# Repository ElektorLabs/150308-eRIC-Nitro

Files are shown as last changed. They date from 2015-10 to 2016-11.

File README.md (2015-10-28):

150308 eRIC Nitro
=================

Arduino Micro compatible module with on-board LPRS eRIC low-power smart radio module. 
Supports eRIC4 (433 MHz) and eRIC9 (865/915 MHz) modules.

The board offers several operating modes:

- MCU controls eRIC through hardware UART

- MCU controls eRIC through software UART

- MCU cooperates with eRIC, eRIC controlled by PC 

Note that eRIC modules can function fully stand-alone, without any help from a
microcontroller. This board can handle that too.

The board is included in the Elektor Arduino Boards Package available at https://github.com/ElektorLabs/Arduino/

www.elektor-labs.com/eric-nitro

www.elektor.com

www.elektor-magazine.com

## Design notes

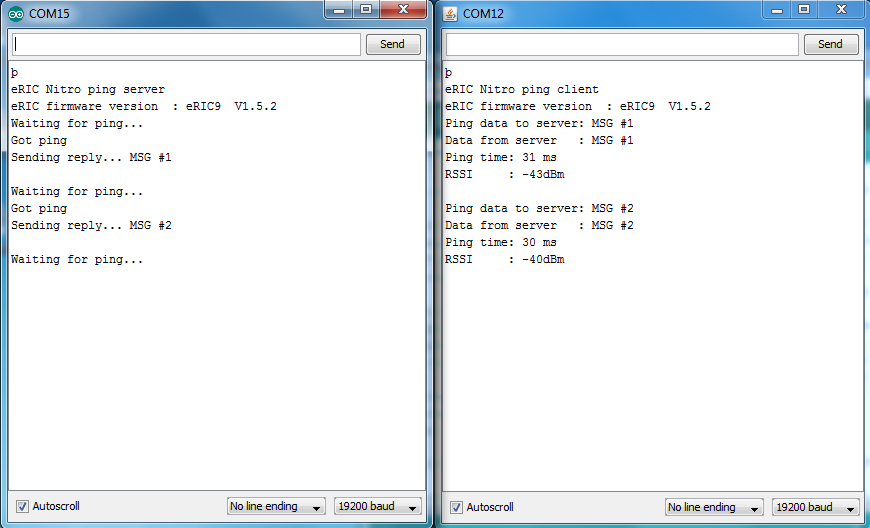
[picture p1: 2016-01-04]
Software/Arduino/eRIC_ping_server/TerminalImages.png

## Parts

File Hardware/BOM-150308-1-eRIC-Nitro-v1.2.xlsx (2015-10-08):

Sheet: BOM
BOM::150308-1::eRIC Nitro::v1.2
Description | Manufacturer | Reference | Footprint | Designation | Qnt | Farnell | Digikey | RS | BOMformul | Comments | BOM for editors
Resistor (5%, 50 V, 0.1 W, 0603) |  |  |  |  | 72 |  |  |  | Resistor (5%, 50 V, 0.1 W, 0603)
100 Ω | Bourns | CR0603-JW-102GLF | 0603-RES | R5, R6 | 2 | 2008355 |  |  | R5, R6 = 100 Ω
1 kΩ | Bourns | CR0603-JW-101GLF | 0603-RES | R1 | 1 | 2008349 |  |  | R1 = 1 kΩ
10 kΩ | Bourns | CR0603-JW-103ELF | 0603-RES | R2, R4, R7 | 3 | 2008360 |  |  | R2, R4, R7 = 10 kΩ
10 kΩ | Bourns | CR0603-JW-103ELF | 0603-RES | R3 | Not loaded | 2008360 |  |  | R3 = 10 kΩ
Capacitor |  |  |  |  | 34 |  |  |  | Capacitor
100 nF, 0603 | Multicomp | MC0603B104K500CT | 0603-CAP | C1, C2, C3, C4, C5, C6 | 6 | 1759122 |  |  | C1, C2, C3, C4, C5, C6 = 100 nF, 0603
10 µF, 16 V, tantalum | Kemet | T491A106K016AT | EIA3216 | C7, C8 | 2 | 1457414 |  |  | C7, C8 = 10 µF, 16 V, tantalum
Inductor |  |  |  |  | 23 |  |  |  | Inductor
10 µH, 0603 | TDK | MLZ1608M100WT | 0603-CAP | L1 | 1 | 2215635 |  |  | L1 = 10 µH, 0603
Semiconductor |  |  |  |  | 1 |  |  |  | Semiconductor
ATmega328P-AU | Atmel | ATMEGA328P-AU | TQFP32-08 | IC1 | 1 | 1715486 |  |  | IC1 = ATmega328P-AU
MIC5205-3.3 | Micrel | MIC5205-3.3YM5 TR | SOT23-5 | IC2 | 1 | 1663083 |  |  | IC2 = MIC5205-3.3
RB751 | ON Semiconductor | RB751S40T1G | SOD-523 | D1, D2, D3 | 3 | 2317437 |  |  | D1, D2, D3 = RB751
LED, green, 0603 | Kingbright | KPT-1608SGC | 0603-LED-ALT1 | LED1 | 1 | 2099223 |  |  | LED1 = LED, green, 0603
Misc. |  |  |  |  | 14 |  |  |  | Misc.
Resonator 8 MHz, SMT | Murata | CSTCE8M00G52-R0 | RESONATOR-SMD-1:1 | X1 | 1 | 2443268 |  |  | X1 = Resonator 8 MHz, SMT
Pin header, 1x12, 0.1" pitch | Wurth | 61301211121 | 1X12 | K1, K2 | 2 | 2356162 |  |  | K1, K2 = Pin header, 1x12, 0.1" pitch
Pin header, 1x2, 0.1" pitch | Wurth | 61300211121 | 1X02 | K3 | 1 | 2356153 |  |  | K3 = Pin header, 1x2, 0.1" pitch
Pin header, 1x2, 0.1" pitch | Wurth | 61300211121 | 1X02 | JP1 | 1 | 2356153 |  |  | JP1 = Pin header, 1x2, 0.1" pitch
Jumper, 2 way, 0.1", for JP6 | FCI | 68786-302LF | n/a |  | 1 | 1740371 |  |  | Jumper, 2 way, 0.1", for JP6
Pin header, 1x4, 0.1" pitch | Wurth | 61300411121 | 1X04 | K5 | 1 | 2356155 |  |  | K5 = Pin header, 1x4, 0.1" pitch
Pin header, 1x6, 0.1" pitch | Wurth | 61300611121 | 1X06 | K4 | 1 | 2356158 |  |  | K4 = Pin header, 1x6, 0.1" pitch
SMA edge connector | Molex | 73251-2120 | SMA-EDGE | K6 | 1 | 1909303 |  |  | K6 = SMA edge connector
Tactile switch | Multicomp | TM-533I-Q-T/R | TACTILE-SWITCH-SMD-ALT01 | S1 | 1 | 9471880 |  |  | S1 = Tactile switch
SP3T Slide Switch | C&K Components | AYZ0203AGRLC | AYZ0203 | S2 | 1 | 2319975 |  |  | S2 = SP3T Slide Switch
eRIC4 SoC Radio Transceiver | LPRS | ERIC4 | ERIC | MOD1 | 1 | 2362439 |  |  | MOD1 = eRIC4 SoC Radio Transceiver
eRIC9 SoC Radio Transceiver | LPRS | ERIC9 | ERIC | MOD1 | 1 | 2362440 |  |  | MOD1 = eRIC9 SoC Radio Transceiver
PCB 150308-1 v1.2 | Elektor | 150308-1 | n/a |  | 1 | n/a |  |  | PCB 150308-1 v1.2
Firmware 150308-11 | Elektor | 150308-11 |  |  | 1 |  |  |  | Firmware 150308-11
GREEN lines for board loaded with eRIC4 module.
BLUE lines for board loaded with eRIC9 module.

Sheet: history
DOCUMENT HISTORY
Date | Rev. | Author | Description

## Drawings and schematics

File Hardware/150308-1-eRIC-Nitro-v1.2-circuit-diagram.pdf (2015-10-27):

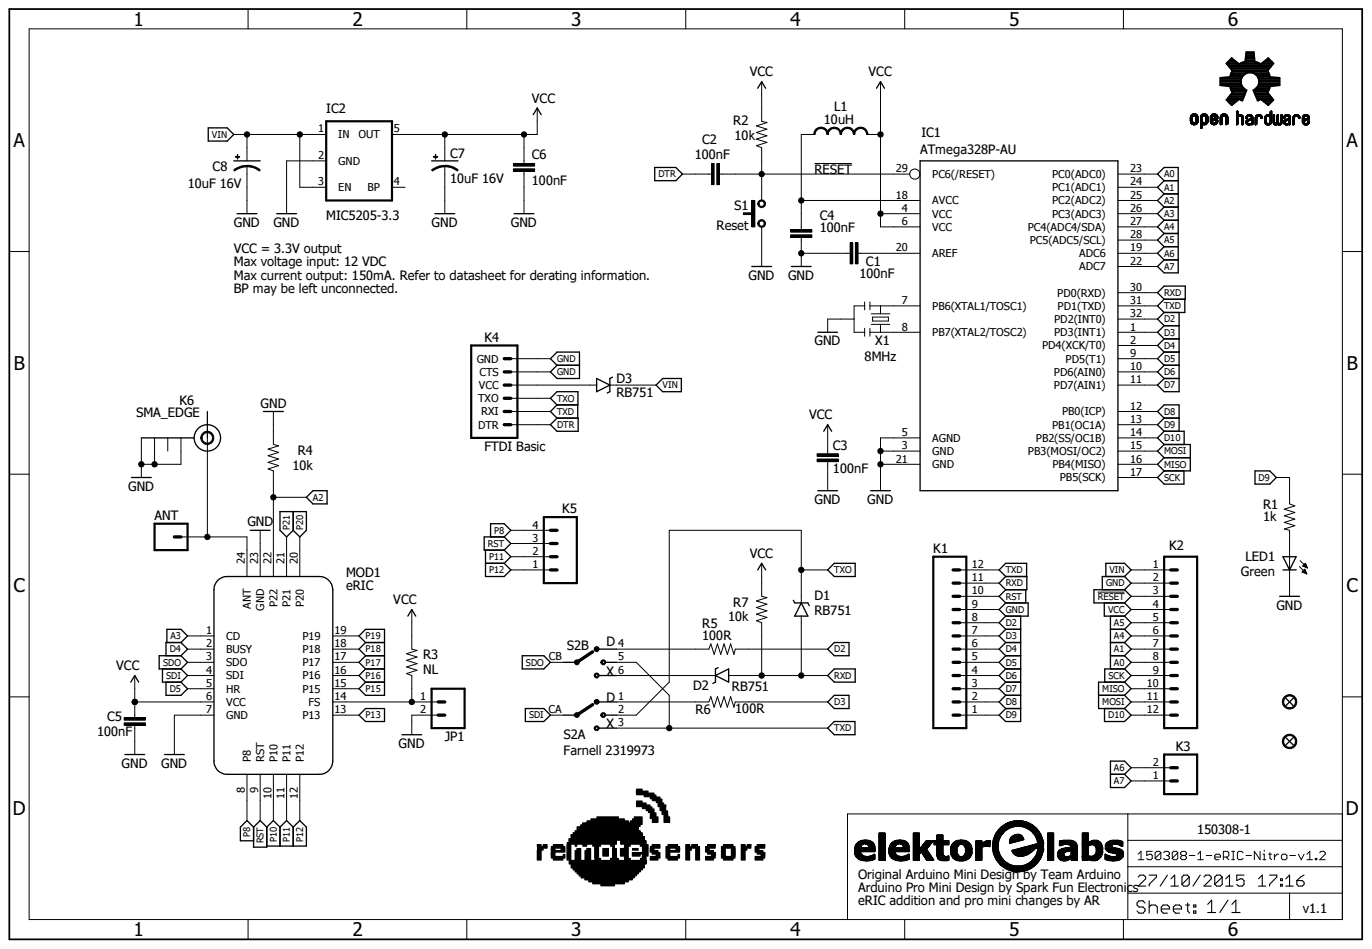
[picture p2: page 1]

VCC = 3.3V output
Max voltage input: 12 VDC
Max current output: 150mA. Refer to datasheet for derating information.
BP may be left unconnected.

Original Arduino Mini Design by Team Arduino
Arduino Pro Mini Design by Spark Fun Electronics
eRIC addition and pro mini changes by AR

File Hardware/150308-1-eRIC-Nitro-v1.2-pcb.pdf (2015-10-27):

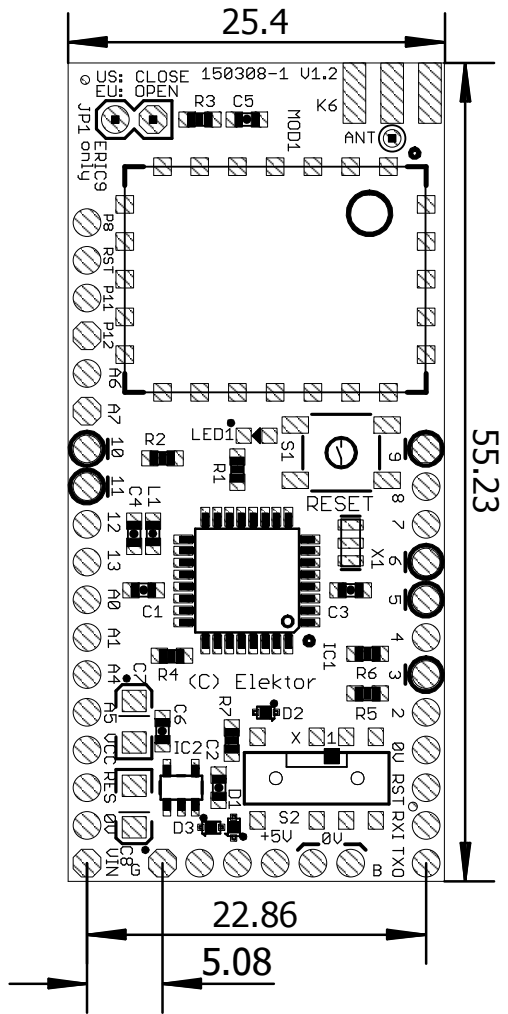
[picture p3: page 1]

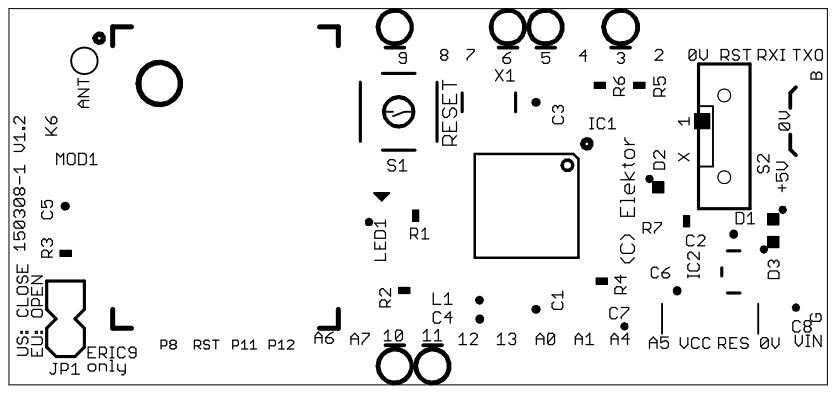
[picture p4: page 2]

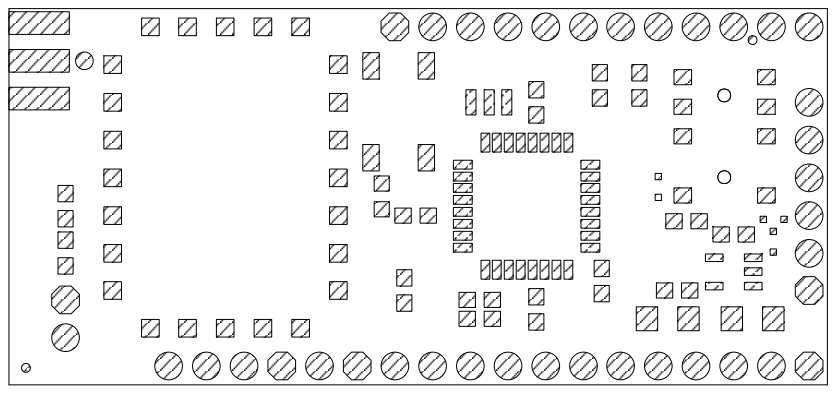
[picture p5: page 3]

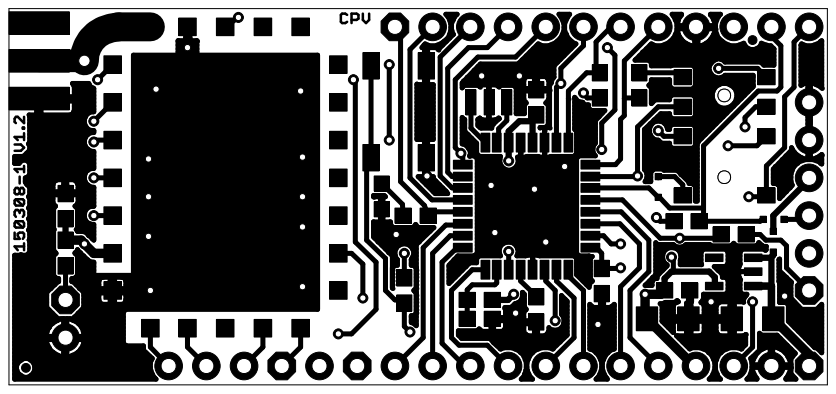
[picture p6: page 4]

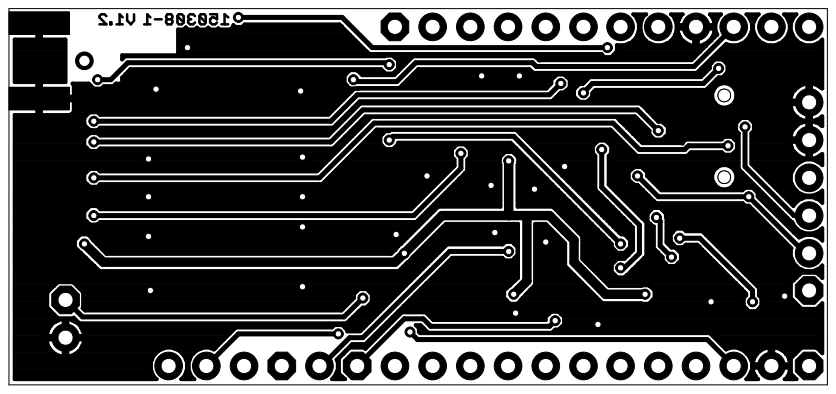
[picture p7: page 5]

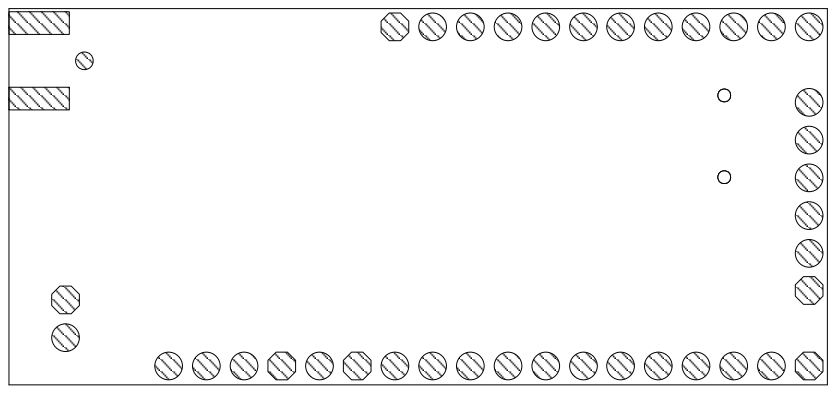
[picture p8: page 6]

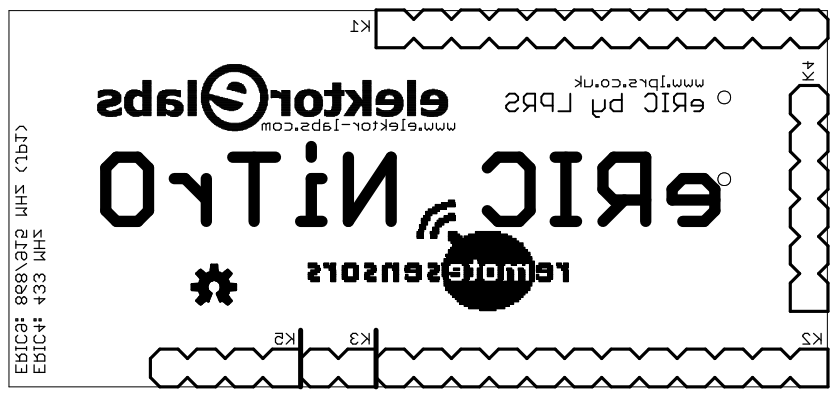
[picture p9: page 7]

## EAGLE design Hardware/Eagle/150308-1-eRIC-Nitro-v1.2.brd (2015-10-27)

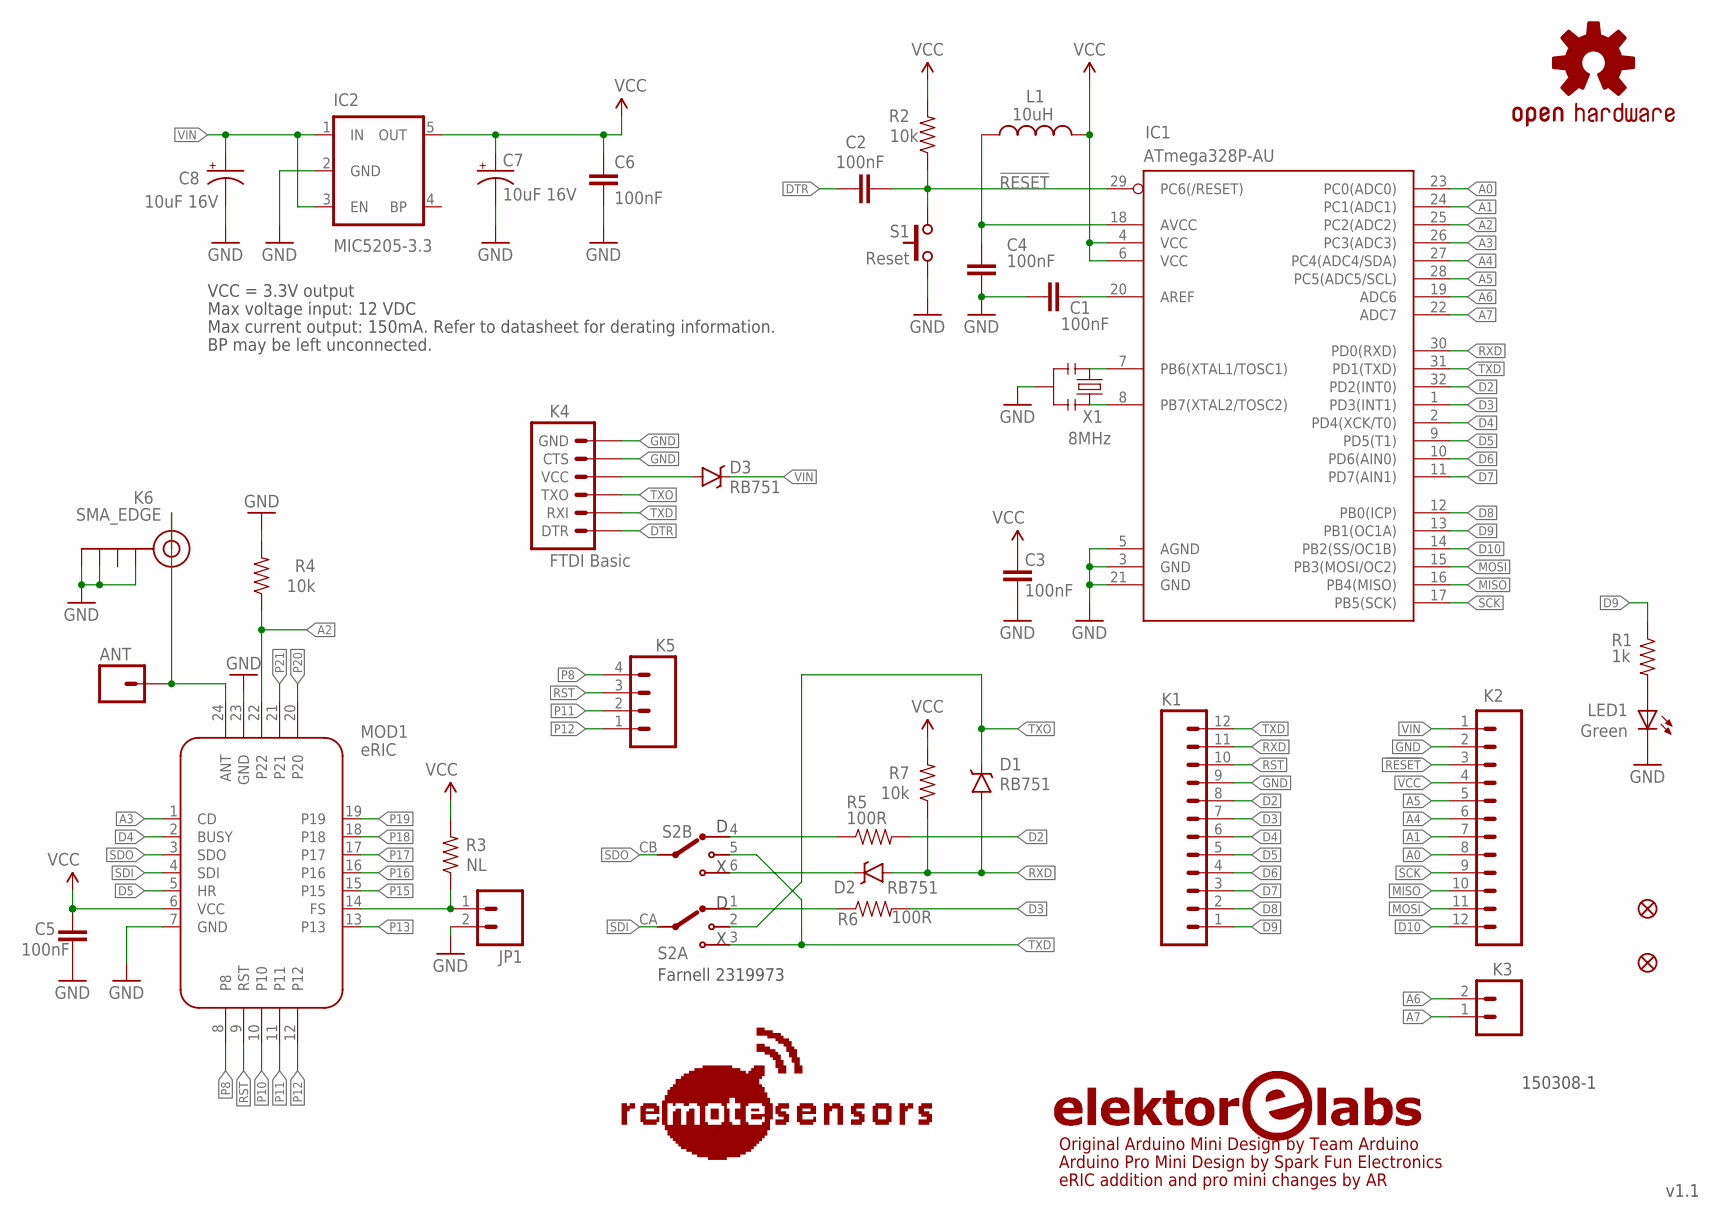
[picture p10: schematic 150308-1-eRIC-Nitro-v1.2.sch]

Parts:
ANT: M01PTH; 1X01-080
C1, C2, C3, C4, C5, C6: 100nF; 0603-CAP
C7, C8: 10uF 16V; EIA3216
D1, D2, D3: RB751; SOD-523
FID1, FID2: FIDUCIALUFIDUCIAL; MICRO-FIDUCIAL
IC1: ATmega328P-AU; TQFP32-08
IC2: MIC5205-3.3; SOT23-5
JP1: M02PTH; 1X02
K1, K2: M12PTH; 1X12
K3: M02PTH; 1X02
K4: FTDI Basic; 1X06
K5: M04PTH; 1X04
K6: SMA_EDGE; SMA-EDGE
L1: 10uH; 0603
LED1: Green; 0603-LED-ALT1
LOGO1: OSHW-LOGOS; OSHW-LOGO-S
LOGO2: LOGO-ELEKTOR-LABS-25MM; ELPP-LOGO-ELEKTOR-LABS-25MM
LOGO3: LOGO-REMOTE-SENSORS-17MM; LOGO-REMOTE-SENSORS2
MOD1: eRIC; ERIC
R1: 1k; 0603-RES
R2, R4, R7: 10k; 0603-RES
R3: NL; 0603-RES
R5, R6: 100R; 0603-RES
S1: Reset; TACTILE-SWITCH-SMD-ALT04
S2: AYZ0203AGRLC; AYZ0203
X1: 8MHz; RESONATOR-SMD

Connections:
!RESET!: C2.1, IC1.29 (PC6(/RESET)), K2.3, R2.1, S1.3 (2), S1.4 (2)
A0: IC1.23 (PC0(ADC0)), K2.8
A1: IC1.24 (PC1(ADC1)), K2.7
A2: IC1.25 (PC2(ADC2)), MOD1.22, R4.1
A3: IC1.26 (PC3(ADC3)), MOD1.1 (CD)
A4: IC1.27 (PC4(ADC4/SDA)), K2.6
A5: IC1.28 (PC5(ADC5/SCL)), K2.5
A6: IC1.19 (ADC6), K3.2
A7: IC1.22 (ADC7), K3.1
ANTENNE: ANT.1, K6.SIG (SIGNAL), MOD1.24 (ANT)
D2: IC1.32 (PD2(INT0)), K1.8, R5.2
D3: IC1.1 (PD3(INT1)), K1.7, R6.2
D4: IC1.2 (PD4(XCK/T0)), K1.6, MOD1.2 (BUSY)
D5: IC1.9 (PD5(T1)), K1.5, MOD1.5 (HR)
D6: IC1.10 (PD6(AIN0)), K1.4
D7: IC1.11 (PD7(AIN1)), K1.3
D8: IC1.12 (PB0(ICP)), K1.2
D9: IC1.13 (PB1(OC1A)), K1.1, R1.1
D10: IC1.14 (PB2(SS/OC1B)), K2.12
DTR: C2.2, K4.1 (DTR)
FS: JP1.1, MOD1.14 (FS), R3.1
GND: C1.1, C3.1, C4.1, C5.1, C6.2, C7.C (-), C8.C (-), IC1.3 (GND), IC1.5 (AGND), IC1.21 (GND), IC2.2 (GND), JP1.2, K1.9, K2.2, K4.5 (CTS), K4.6 (GND), K6.GND@0 (GND), K6.GND@2 (GND), K6.GND@3 (GND), LED1.C, MOD1.7 (GND), MOD1.23 (GND), R4.2, S1.1, S1.2 (1), X1.2
MISO: IC1.16 (PB4(MISO)), K2.10
MOSI: IC1.15 (PB3(MOSI/OC2)), K2.11
unnamed: IC1.8 (PB7(XTAL2/TOSC2)), X1.3
unnamed: IC1.7 (PB6(XTAL1/TOSC1)), X1.1
unnamed: C1.2, IC1.20 (AREF)
unnamed: C4.2, IC1.18 (AVCC), L1.1
unnamed: LED1.A, R1.2
unnamed: D3.A, K4.4 (VCC)
unnamed: R5.1, S2.4 (1)
unnamed: D2.C, S2.6 (3)
unnamed: R6.1, S2.1
P8: K5.4, MOD1.8
P10: MOD1.10
P11: K5.2, MOD1.11
P12: K5.1, MOD1.12
P13: MOD1.13
P15: MOD1.15
P16: MOD1.16
P17: MOD1.17
P18: MOD1.18
P19: MOD1.19
P20: MOD1.20
P21: MOD1.21
RST: K1.10, K5.3, MOD1.9 (RST)
RXD: D1.A, D2.A, IC1.30 (PD0(RXD)), K1.11, R7.1
SCK: IC1.17 (PB5(SCK)), K2.9
SDI: MOD1.4 (SDI), S2.CA (2)
SDO: MOD1.3 (SDO), S2.CB (2)
TXD: IC1.31 (PD1(TXD)), K1.12, K4.2 (RXI), S2.3, S2.5 (7)
TXO: D1.C, K4.3 (TXO), S2.2 (7)
VCC: C3.2, C5.2, C6.1, C7.A (+), IC1.4 (VCC), IC1.6 (VCC), IC2.5 (OUT), K2.4, L1.2, MOD1.6 (VCC), R2.2, R3.2, R7.2
VIN: C8.A (+), D3.C, IC2.1 (IN), IC2.3 (EN), K2.1

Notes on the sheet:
Original Arduino Mini Design by Team Arduino
Arduino Pro Mini Design by Spark Fun Electronics
Max voltage input: 12 VDC
Max current output: 150mA. Refer to datasheet for derating information.
VCC = 3.3V output
eRIC addition and pro mini changes by AR
Farnell 2319973
BP may be left unconnected.

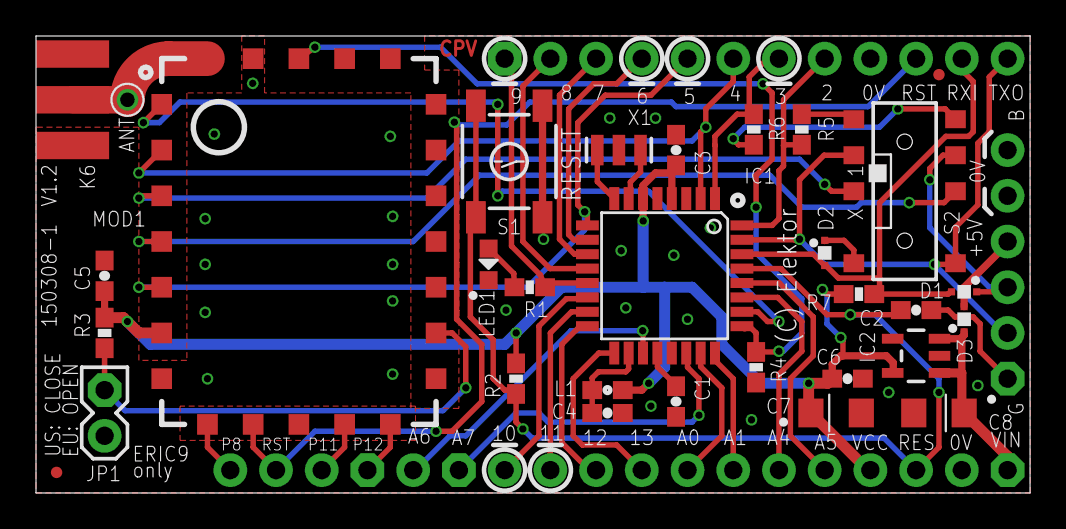
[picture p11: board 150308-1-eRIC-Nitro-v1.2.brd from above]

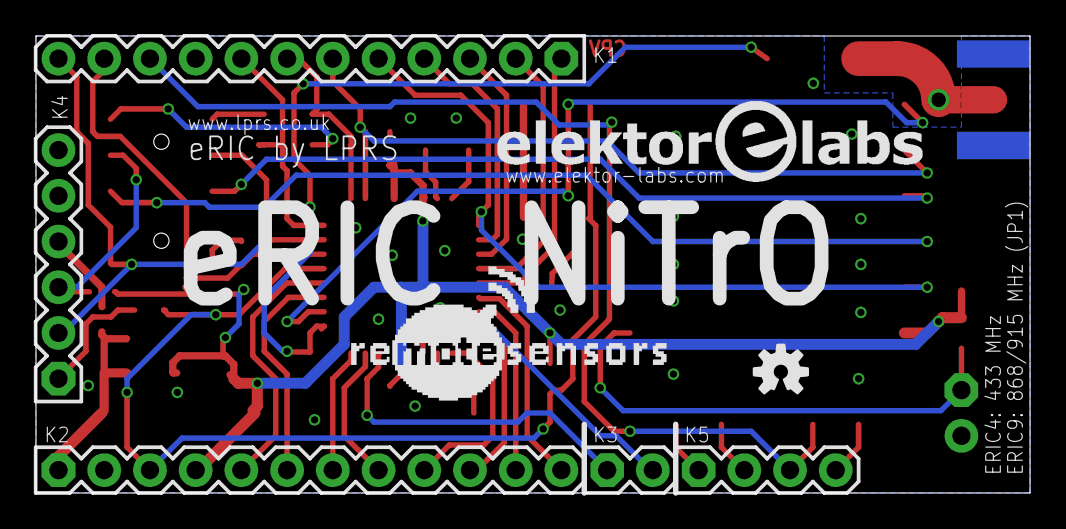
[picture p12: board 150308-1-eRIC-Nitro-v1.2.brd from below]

Board: 2 copper layers, 55.2 x 25.4 mm, 39 parts (8 on the bottom side), 45 nets.

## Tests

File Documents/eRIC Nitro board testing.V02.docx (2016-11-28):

# 1 Introduction

The purpose of this document is to describe how to configure the Nitro board for use with the LPRS “easyRadio Companion software” while describing a test sequence to verify the assembly of the eRIC Nitro board and to verify the eRIC module is capable of transmitting and receiving data from another eRIC module.

# 2 eRIC Nitro board testing

Suggested test sequence,

a) Test the eRIC module in standalone mode
b) Test the Arduino in standalone mode
c) Test the Arduino communication with the eRIC using Arduino software UART
d) Test the Arduino communication with the eRIC using Arduino hardware UART

## 2.1 Test setup – eRIC module in standalone mode

To test eRIC module in standalone mode on Nitro board (verifying part of the eRIC PCB design and PCB assembly), requires,

a) 1 x assembled Nitro board, fully populated including all components including SIL headers strip and wire antenna (see later)
b) 1 x FTDI – USB-serial cable (USB to UART cable with +3.3V TTL level UART signals e.g. Farnell TTL-232R-3V3 http://bit.ly/2gryNGJ )
c) 1 x female-female jumper or jumper cable
d) 1 x Windows PC
e) 1 x LPRS easyRadio Companion software (see later)

# 3 Test Procedure – step 1

1. At this point it is assumed that the Nitro board has been checked to confirm (at least) there are no short circuits between Nitro board Vin and GND (0V) pins and 3.3V and GND(0V) pins.
2. The LPRS website page http://www.lprs.co.uk/resource-centre/downloads/eric-software-datasheets/eros-4-files.html contains the documentation and software for the eRIC module

Download and install the easyRadio software from http://www.lprs.co.uk/assets/media/easyRadiosetup%204.0.5.exe

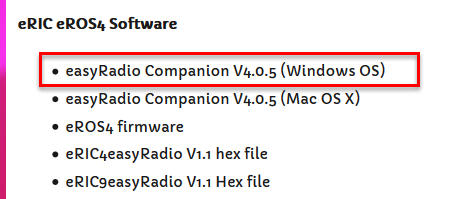
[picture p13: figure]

3. Get your FTDI cable ready. Don’t connect it to the Nitro or PC just yet and make sure there is no power applied to the board.
4. Get the Nitro board ready as follows,
a) Populate the Nitro board FTDI header (K4) with a male 6 pin header so that it can mate with the female end of a FTDI connector. The board below shows a SMA connector (6) added to the board but this is not necessary if using only a wire antenna

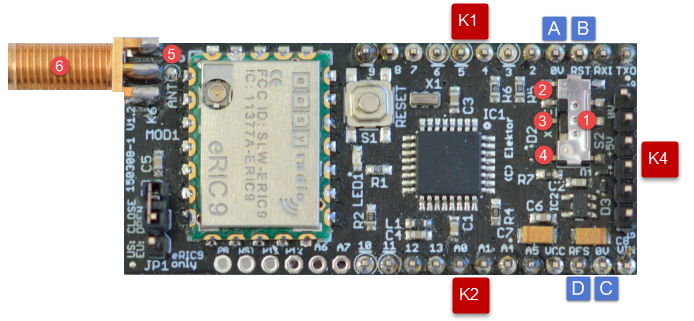
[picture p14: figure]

b) There are 2 options for a board level antenna. Either connect an SMA antenna (to 6) or solder a simple (¼ wavelength) wire antenna to the board (at 5). The antenna length for an eRIC9 module is 86mm. For a eRIC4 module it is 173mm.

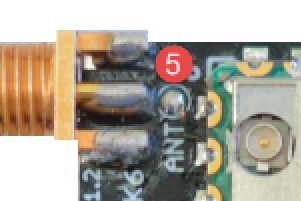
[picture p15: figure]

c) Using a jumper, connect the Nitro RES pin (D) to 0V (C), as this will force all ATMega328 pins into high impedance state when power is finally applied to the board.
  - Note: there is a separate reset pin (B) RST for the eRIC module. Leave this unconnected and do not confuse it with RES pin (D), which is the ATMega328 reset pin.
d) Put Nitro board switch S2 (1) into middle position (3) so that the SDO/SDI pins of the eRIC are directly connected to the FTDI header (K4) RXI/TXO pins, bypassing the ATMega328 RXD/TXD pins.

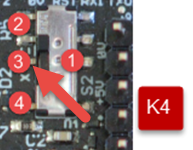
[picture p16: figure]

e) Connect the FTDI cable to the Nitro FTDI header (K4). Pay special attention to make sure the cable header polarity is correct – the FTDI GND pin (black cable) must mate with the Nitro FTDI header (K4) GND pin, and the FTDI +5V/VCC pin (red cable) must mate with the Nitro FTDI header (K4) +5V/VCC pin. Once this is done, connect USB end of FTDI cable to computer USB port. This will power up the Nitro board including the eRIC.

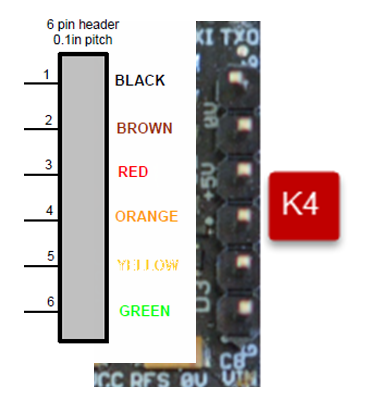
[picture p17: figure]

5. Start the easyRadio software

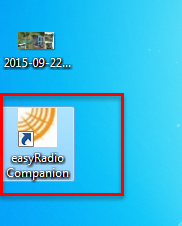
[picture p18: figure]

6. This will open a dialog box, but you can select “Not Now” to skip this section

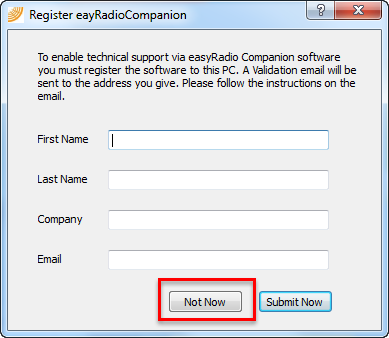
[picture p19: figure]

7. Select eRIC radio button (1) and then “OK” button (2) to select the eRIC module

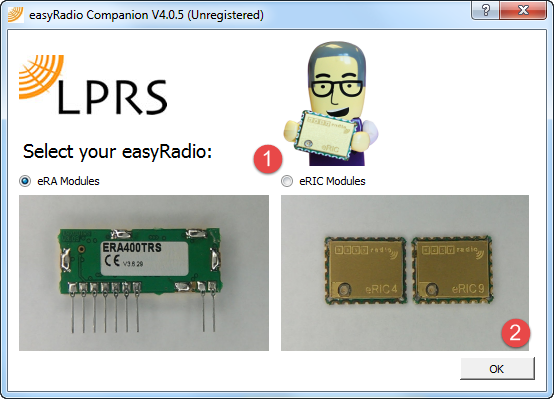
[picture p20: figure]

8. Next setup the FTDI serial connection settings from within the easyRadio software.
a) Select the appropriate port from drop down list (1)
b) Leave the baud rate(2) at whatever value it is set at, since the easyRadio software will try and auto detect the eRIC baud rate, and the value (2) may change.
c) Set handshaking as none (3)
d) Click on the “Open port” button to open the FTDI virtual COM port (4).

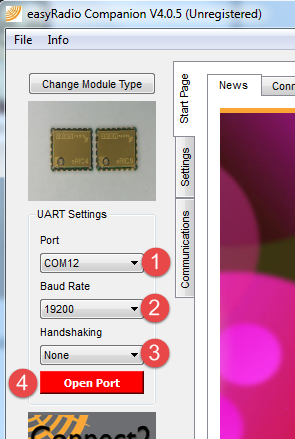
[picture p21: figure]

9. Click on the settings (1) and the then the module info (2) tabs.

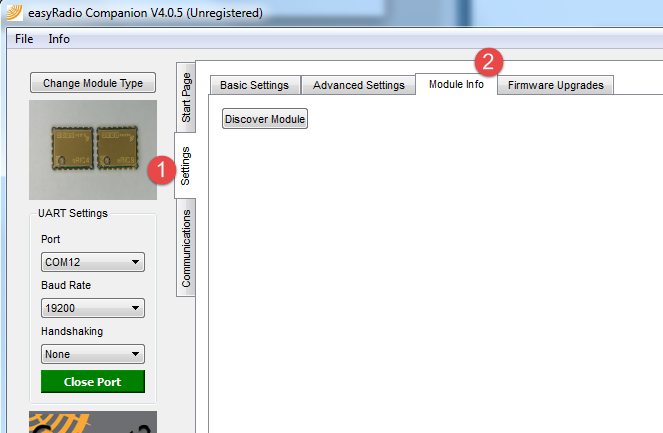
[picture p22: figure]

10. Click on “Discover Module” (1). The easyRadio software will try and autobaud connect to the eRIC module on the specified port.


If all is okay (i.e. eRIC not dead, no problems with FTDI cable TXD/RXD to eRIC SDI/SDO connections or power to eRIC etc.), then you should see a screen similar to the one below, where all of the information related to App Code, OS, BSL etc. has been read from the eRIC module over the FTDI TXD/RXD interface.


This is a good sign that the basic eRIC-FTDI electrical connections are good. To verify the PCB design and assembly further needs a second eRIC module and another set of test steps. See next section.

# 4 Test Procedure – step 2

Step 2 requires another Nitro board to be assembled and tested as per step 1. This will require a second FTDI cable and a second female-female jumper.

Confirm the 2nd Nitro board hardware by repeating actions 1, 3-10 from step 1 above. No action 2 is necessary if the easyRadio software has already been downloaded and installed. Both Nitro boards must be of same type i.e. both eRIC4, or both eRIC9, and both must have same firmware revision.

We can now test the RF interface.

1. Close all instances of the easyRadio software.
2. Remove FTDI cables from PC.
3. Connect first FTDI cable to 1st Nitro board and insert FTDI cable USB to PC.
4. Connect second FTDI cable to 2nd Nitro board and insert FTDI cable USB to PC.
5. Keep both Nitro board at least 30cm apart to avoid RF swamping i.e. avoid overloading Nitro 2 radio receiver with too large a signal from Nitro 1.
6. Open easyRadio software and repeat action 6, 7, 8 for 1st module. Then select communications tab (1)


7. Open second instance of easyRadio software and repeat action 6, 7, 8 for 2nd module. Then select communications tab (1) again in second instance. On your screen you might see something like this, (In this image we have 2 Nitro boards connected to COM port 12 and 15 on the test PC.)


8. On 1st instance of software at (1) type in a message to be sent to 2nd Nitro board, then click on Send button (2). If all is okay and Nitro 2 is receiving , then the message from Nitro 1 should appear on Nitro 2 at (3)


# 5 Document revisions

Revision | Description
V01 | Initial version
V02 | Updated to clarify switch and jumper configuration for eRIC Nitro use with LPRSTM easyRadio Companion software

=== end of document ===

eRIC Nitro Board testing and LPRS easyRadio Companion software setup V02

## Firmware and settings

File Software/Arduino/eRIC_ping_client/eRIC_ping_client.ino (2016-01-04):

/*
 * Part of Elektor project 150308 eRIC Nitro.
 *
 * Put S2 in position 'X'.
 * Software serial port on pins 2 & 3.
 * 3.3 V FTDI compatible USB-to-serial converter connected to K1 (D2, D3, GND),
 * +5V connected to K4 pin 4.
 * 
 * Sends ping messages to eRIC Nitro server. Receives returned ping from server
 * and prints time for transmit-receive round trip and also the received signal
 * strength of received message.
 * Does not use any hardware flow control between MCU and eRIC module.
 *
 * MCU communicates with eRIC module through hardware UART.
 * MCU communicates with PC through software UART.
 * Serial port settings: 19200n81
 *
 * AR, 03/01/2016
 *
 * Copyright (c) 2016 Elektor (www.elektor.com, www.elektor-labs.com).
 * All right reserved.
 *
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
 * You should have received a copy of the GNU Lesser General Public
 * License along with this library; if not, write to the Free Software
 * Foundation, Inc., 51 Franklin St, Fifth Floor, Boston, MA  02110-1301  USA
 */
/* 
 * Put S2 in position 'X' (close to D1).
 * Software serial port on pins 2 & 3.
 * 
 * Sends all known queries to eRIC module, one per second,
 * and forwards response to PC.
 */

#include <SoftwareSerial.h>

#define TIMEOUT                1000 
  // Timeout value - 1000milliseconds
#define ERIC_CMD_FIRMWARE      "ER_CMD#T3"
  // eRIC OS command to read module firmware version
#define ERIC_CMD_RSSI          "ER_CMD#T8"
  // eRIC OS command to read last message RSSI
#define ACK                    1
#define NO_ACK                 0
#define MAX_RF_PAYLOAD_SIZE    32 
  // We only want to use a small RF payload.
  // eRIC module can handle much larger RF payloads than this
#define ERROR_OK               1
#define ERROR_TIMEOUT          2
#define ERROR_CMD_NOT_RETURNED 3
#define ERROR_DATA_FORMAT      4

// Declare local RF data receive and transmit buffers
char abTxData[MAX_RF_PAYLOAD_SIZE];
char abRxData[MAX_RF_PAYLOAD_SIZE];

int iMessageNumber = 0;

// Declare SoftwareSerial object. Will be used by MCU to 
// communicate with eRIC module
SoftwareSerial soft_serial(2,3); // RX, TX

void setup(void)
{
  int iStatus;
 
  // Give everybody some time to initialise.
  delay(500);
  
  // Initialise hardware usart with 19200 bps baud rate
  Serial.begin(19200);
  Serial.println();
  Serial.println(F("eRIC Nitro ping client"));
  
  // Software serial port on pins 2 & 3.
  // Put S2 in position 'D'.
  soft_serial.begin(19200);
  
  // Send command to eRIC module to read module firmware
  // version
  iStatus = eRIC_SendCommand(ERIC_CMD_FIRMWARE, 
                             ACK, 
                             abRxData, 
                             sizeof(abRxData));
  
  // Was the command processed correctly by the eRIC module?
  if (iStatus == ERROR_OK)
  {
    // Command processed correctly. Print firmware version
    Serial.print(F("eRIC firmware version  : "));
    Serial.println(abRxData);
  }
  else
  {
    // Command was not processed correctly. 
    // Print error message and hang the MCU
    Serial.println(F("Can't communicate with eRIC module. Program halted."));
    Serial.println(F("Check wiring and eRIC baud rate."));
    while (1)
    {
      ;
    }
  }
}

void loop(void)
{
  unsigned long ulSendStartTime;
  unsigned long ulPingTime;  
  
  // Clear local receive buffer
  memset(abRxData, '\0', sizeof(abRxData));
  
  // Increment message number and reset to 0, if
  // it rolls over to a negative value
  iMessageNumber++;
  if(iMessageNumber < 0)
  {
    iMessageNumber = 0;  
  }
  
  // Create ping message in local buffer abTxData[]
  sprintf(abTxData, "MSG #%d", iMessageNumber);
  
  // Send ping message to eRIC module for transmission 
  // over RF interface
  soft_serial.println(abTxData);
  
  // Start the ping timout timer
  ulSendStartTime = millis();
  
  Serial.print(F("Ping data to server: "));
  Serial.println(abTxData);
  
  // Loop waiting for server to return message.
  // Loop will exit if message received or there is a timeout
  while(!eRIC_GetData(abRxData, sizeof(abRxData)))
  {
    if (millis() - ulSendStartTime > TIMEOUT) 
    {
      // No response from eRIC so return with diagnostic message
      Serial.println(F("Timeout on response from server!"));
      return;
    }
  }
  
  // Calculate round trip "transmit-receive" ping time
  ulPingTime = millis() - ulSendStartTime;

  // Print data received over RF interface and
  // ping time
  Serial.print(F("Data from server   : "));
  Serial.print(abRxData);
  Serial.print(F("Ping time: "));
  Serial.print(ulPingTime);
  Serial.println(F(" ms"));
  
  // Send RSSI command to from eRIC module OS
  // Was the command processed correctly by the eRIC module?
  if (eRIC_GetRSSI(abRxData, sizeof(abRxData)) == ERROR_OK)
  {
    // Command was  processed correctly. 
    // Print RSSI value
    Serial.print(F("RSSI     : "));
    Serial.println(abRxData);
  }
  else
  {
    // Command was  not processed correctly. 
    // Print error message
    Serial.println(F("No RSSI response from eRIC"));
  }
  
  Serial.println();
  delay(3000);
}

// Get received RF data from eRIC module
int eRIC_GetData(char *abRxData, int iRxLength)
{
  int iCount;
    
  if(iRxLength <= 0) 
  {
    // Return length of 0
    return 0;
  }
  
  if(!soft_serial.available()) 
  {
    // Return length of 0
    return 0;
  }
  
  // If eRIC has received data over RF interface, read it 
  iCount = 0;
  while(soft_serial.available() && (iCount < iRxLength)) 
  {
    // Save RF data byte received by eRIC module into abRxData[] 
    abRxData[iCount++] = soft_serial.read();
  }
  
  // Return number of bytes received
  return iCount;
}

// Send eRIC OS command to eRIC module
// Returns : ERROR_OK - command processed correctly by eRIC OS
//           ERROR_TIMEOUT - eRIC OS did not reply withing timeout period
int eRIC_SendCommand(char *abCommand, int iACKrequired, char *abRxData, int iRxLength)
{
  int iPosition = 0;
  unsigned long ulSendStartTime;
  char abBuffer[MAX_RF_PAYLOAD_SIZE];
 
  // Initialise local variables
  memset(abBuffer, 0, sizeof(abBuffer));  
    
  // Send command to eRIC
  soft_serial.print(abCommand);
  
  ulSendStartTime = millis();
  while(!soft_serial.available())
  {   
    if (millis() - ulSendStartTime > TIMEOUT) 
    {
      // No response from eRIC so return with diagnostic message
      // Serial.println("Cannot communicate with eRIC module.");
      return ERROR_TIMEOUT;
    }
  }
  
  // Read response from eRIC module 
  iPosition = 0;
  while(soft_serial.available()) 
  {
    if (iPosition < (sizeof(abBuffer)- 1))
    {
      abBuffer[iPosition++] = soft_serial.read();
      abBuffer[iPosition] = 0;
    }
  }
  
  // Does command need an "ACK" string to be sent to eRIC 
  // to complete command processing
  if (iACKrequired == ACK)
  {
    // ACK, required. Send ACK string to eRIC module
    soft_serial.print("ACK");
   
    // Start the timeout timer
    ulSendStartTime = millis();
    while(!soft_serial.available())
    {   
      if (millis() - ulSendStartTime > TIMEOUT) 
      {
        // No response from eRIC so return with diagnostic message
        // Serial.println("Cannot communicate with eRIC module.");
        return ERROR_TIMEOUT;
      }
    }
  }
  
  // Read response from eRIC module 
  iPosition = 0;
  while(soft_serial.available()) 
  {
    if (iPosition < (sizeof(abBuffer)- 1))
    {
      abBuffer[iPosition++] = soft_serial.read();
      abBuffer[iPosition] = 0;
    }
  }
  
  // Copy received response to abRxData[]
  memcpy(abRxData, abBuffer, iRxLength);
  return ERROR_OK;
}

int eRIC_GetRSSI(char *abBuffer, int iLength)
{
  int iStatus;
  int iStringLength;
  char abLocalBuffer[MAX_RF_PAYLOAD_SIZE];
  
  // Is the length of abBuffer less than 5 characters?
  if (iLength < 7)
  {
    // Yes, return error code
    return ERROR_DATA_FORMAT;
  }
  
  // Send eRIC command to read module serial number
  iStatus = eRIC_SendCommand(ERIC_CMD_RSSI, ACK, abLocalBuffer, sizeof(abLocalBuffer)); 
 
    // Did the command get processed without error?
  if (iStatus == ERROR_OK)
  {
    // Get length of RSSI string (not including terminating '\0')
    iStringLength = strlen(abLocalBuffer);
      
    // iStringLength does not include length with terminating '\0'
    // Adjust iStringLength so that it does not overflow array abBuffer[]
    if ((iStringLength + 1) > iLength)
    {
      iStringLength = iLength - 1;
    }
    
    // Copy local string to array abBuffer[]
    memcpy(abBuffer, abLocalBuffer, iStringLength);
    
    // Add terminating null character
    abBuffer[iStringLength] = '\0';
  }
    
  return iStatus;
}

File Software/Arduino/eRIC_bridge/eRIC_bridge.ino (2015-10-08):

/*
 * Part of Elektor project 150308 eRIC Nitro.
 *
 * Put S2 in position 'D'.
 * Software serial port on pins 2 & 3.
 * 3.3 V FTDI compatible USB-to-serial converter connected to K4
 * 
 * Sends all known queries - one per second - to eRIC module,
 * responses are forwarded to the PC.
 *
 * MCU communicates with eRIC module through software UART.
 * MCU communicates with PC through hardware UART.
 * Serial port settings: 19200n81
 *
 * CPV, 8/10/2015
 *
 * Copyright (c) 2015 Elektor (www.elektor.com, www.elektor-labs.com).
 * All right reserved.
 *
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
 * You should have received a copy of the GNU Lesser General Public
 * License along with this library; if not, write to the Free Software
 * Foundation, Inc., 51 Franklin St, Fifth Floor, Boston, MA  02110-1301  USA
 */

#include <SoftwareSerial.h>

SoftwareSerial soft_serial(2,3); // RX, TX

int led1 = 9;
int led2 = 13;
uint32_t t_prev;
int eric_cmd;

#define ERIC_COMMANDS  (13)
char *eric_commands[ERIC_COMMANDS] =
{
  "ER_CMD#U?",
  "ER_CMD#P?",
  "ER_CMD#C?",
  "ER_CMD#F?",
  "ER_CMD#f?",
  "ER_CMD#B?",
  "ER_CMD#L7?",
  "ER_CMD#L8?",
  "ER_CMD#L4xx?",
  "ER_CMD#A1?",
  "ER_CMD#A2?",
  "ER_CMD#A5?",
  "ER_CMD#Z0?",
};

void eric_send_command(int n)
{
  soft_serial.print(eric_commands[n]);
  delay(50);
  soft_serial.print("ACK");
}

void led_on(int led, boolean on)
{
  digitalWrite(led,on==true?HIGH:LOW);
}

void led_toggle(int led)
{
  if (digitalRead(led)!=0)
  {
    digitalWrite(led,LOW);
  }
  else
  {
    digitalWrite(led,HIGH);
  }
}

void setup(void)
{
  pinMode(led1,OUTPUT);
  pinMode(led2,OUTPUT);
  led_on(led1,false);
  led_on(led2,false);
  
  Serial.begin(19200);
  Serial.println("eRIC Nitro bridge");

  // Software serial port on pins 2 & 3.
  // Put S2 in position 'D'.
  soft_serial.begin(19200);
  t_prev = 0;
  eric_cmd = 0;

  // Give everybody some time to initialise.
  delay(500);
}

void loop(void)
{
  if (millis()>=t_prev+1000)
  {
    t_prev = millis();
    Serial.println();
    if (eric_cmd<10) Serial.print(" ");
    Serial.print(eric_cmd);
    Serial.print(": ");
    eric_send_command(eric_cmd);
    eric_cmd += 1;
    if (eric_cmd>=ERIC_COMMANDS) eric_cmd = 0;
  }
  
  if (soft_serial.available()) 
  {
    Serial.write(soft_serial.read());
    led_toggle(led1);
  }
  if (Serial.available()) 
  {
    soft_serial.write(Serial.read());
    led_toggle(led2);
  }
}

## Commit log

2015-10-08 Initial commit
    This is pretty much release ready.
    [150308-1-eRIC-Nitro-v1.2.brd, 150308-1-eRIC-Nitro-v1.2.sch, BOM-150308-1-eRIC-Nitro-v1.2.xlsx]
2015-10-27 Small cosmetic changes, new bootloader
    [150308-1-eRIC-Nitro-v1.2.brd, 150308-1-eRIC-Nitro-v1.2.sch]
2015-11-03 Added DesignSpark PCB7 project
    [150308-1-eRIC-Nitro-v1.2.2.sch, 150308-1-eRIC-Nitro-v1.2.brd, 150308-1-eRIC-Nitro-v1.2.sch]

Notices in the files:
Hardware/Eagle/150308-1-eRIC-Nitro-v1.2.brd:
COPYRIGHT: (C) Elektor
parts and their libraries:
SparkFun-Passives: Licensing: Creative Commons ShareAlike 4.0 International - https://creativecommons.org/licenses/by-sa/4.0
